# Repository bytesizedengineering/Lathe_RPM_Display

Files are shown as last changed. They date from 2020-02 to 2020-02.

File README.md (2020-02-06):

# Lathe_RPM_Display

See project on YouTube: https://youtu.be/7gDZs0bImr0
I bought a wood lathe a few months ago and I thought it would be fun to make my own digital readout. 
The plan for this project was to use a hall effect sensor and a neodymium magnet to sense the rotations of the lathe spindle. 
I used an arduino board to read the sensor, count the pulses, and calculate the RPM of the spindle. 
I used seven segment displays to show the RPM reading. I designed a PCB and 3D printed an enclosure.

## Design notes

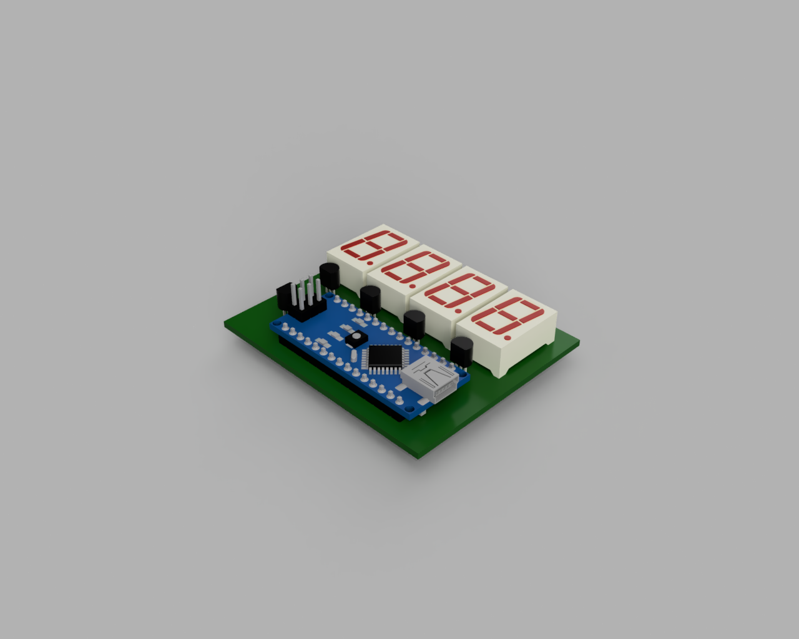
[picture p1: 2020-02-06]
Lathe RPM Display.PNG

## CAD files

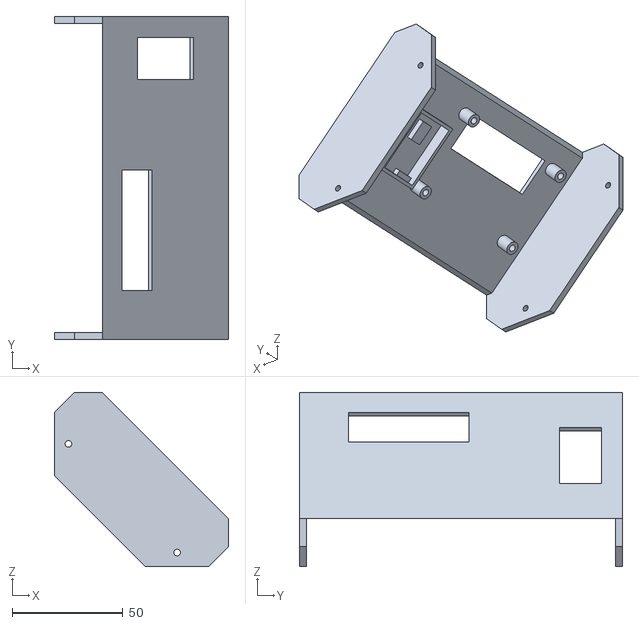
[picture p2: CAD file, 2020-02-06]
CAD/lid.stl
78.7 x 146.0 x 78.7

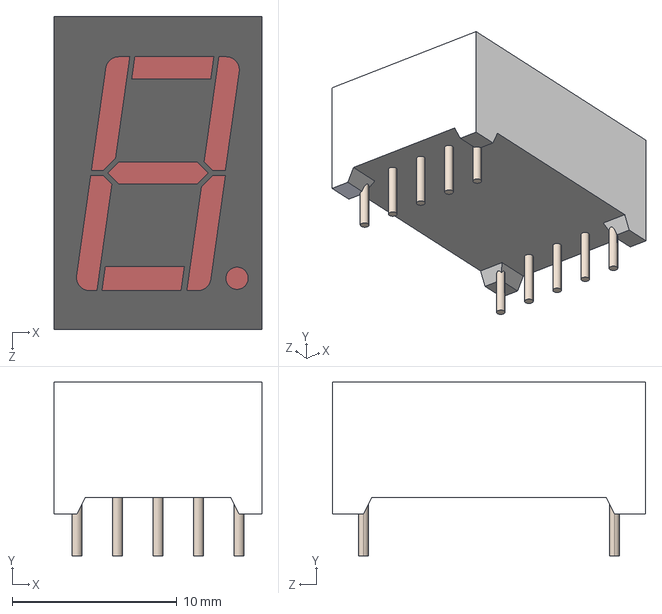
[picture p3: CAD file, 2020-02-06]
PCB/HSR8144B10 7Seg LED.STEP
12.6 x 10.6 x 19.0 mm

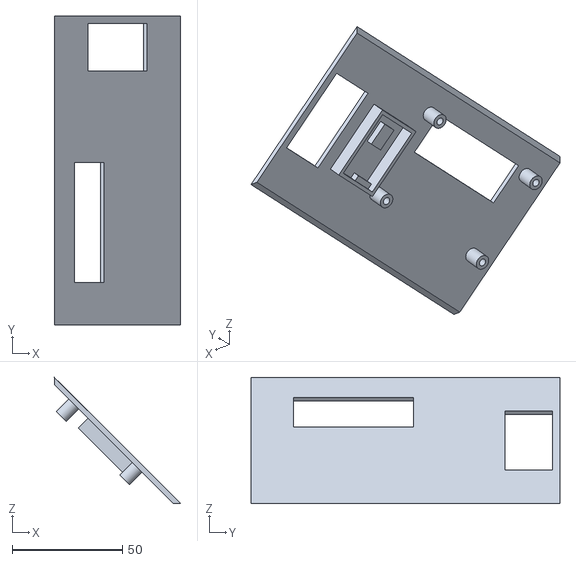
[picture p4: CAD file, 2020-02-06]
CAD/lid test print.stl
57.1 x 139.7 x 57.1

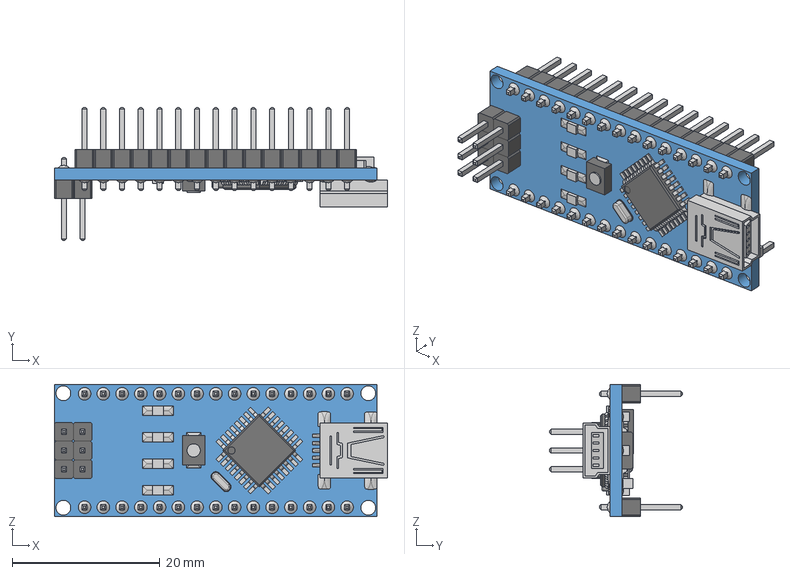
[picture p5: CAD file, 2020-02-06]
PCB/Arduino Nano V3.step
45.1 x 18.0 x 17.9 mm
switch
Led x 3
Led (1)
Pin x 21
chip1
USB
Crystal
Pin (1) x 15
Res x 5
cap x 2
Chip
respack x 2
diode
vreg

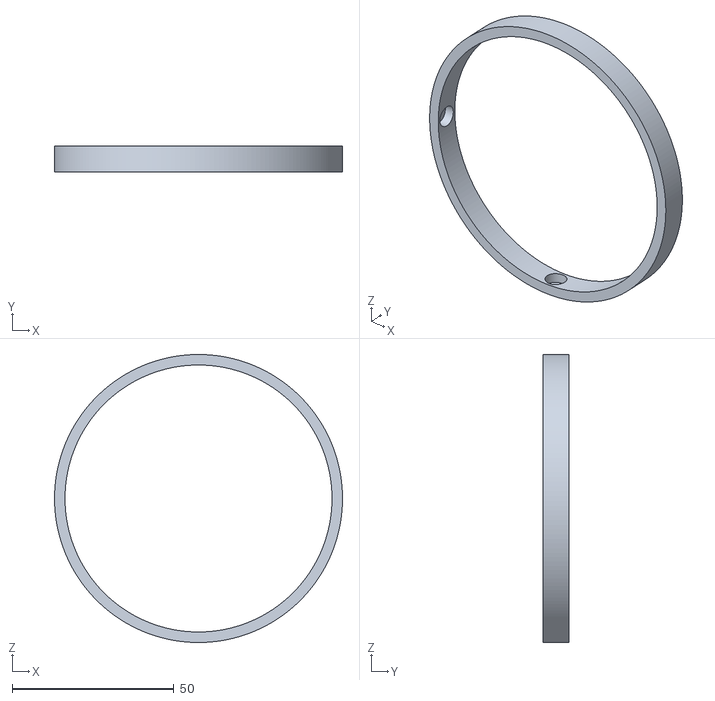
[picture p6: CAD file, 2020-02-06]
CAD/4 magnet ring.stl
89.0 x 8.00 x 89.0

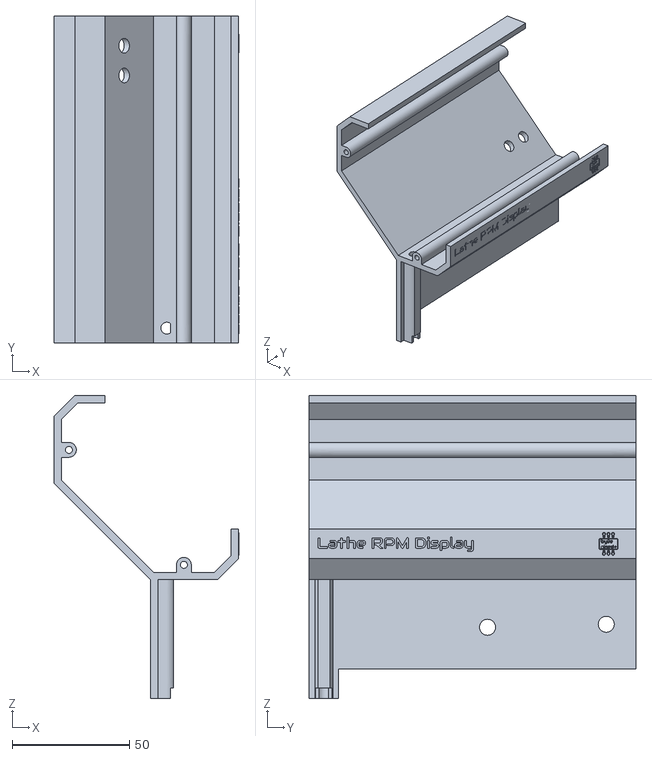
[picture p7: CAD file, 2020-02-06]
CAD/enclosure.stl
79.0 x 139.7 x 129.5

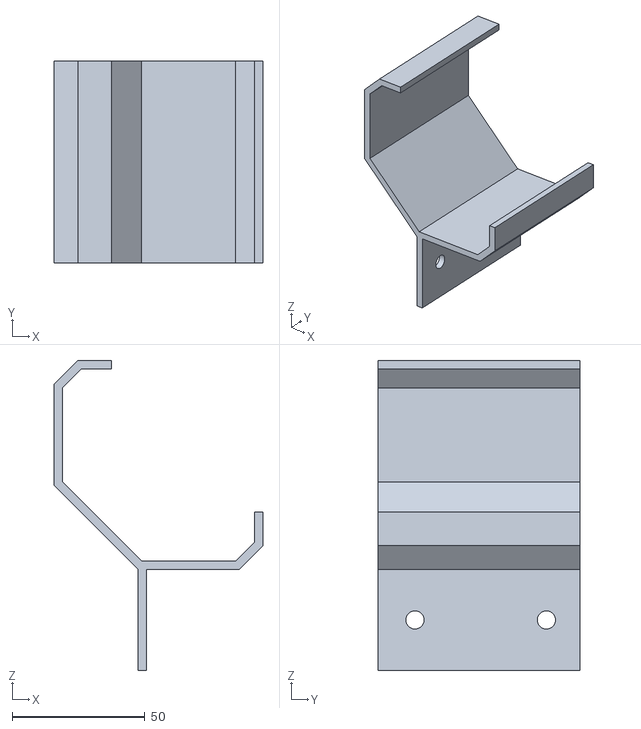
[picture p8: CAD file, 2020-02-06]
CAD/enclosure test print.stl
78.7 x 76.2 x 116.8

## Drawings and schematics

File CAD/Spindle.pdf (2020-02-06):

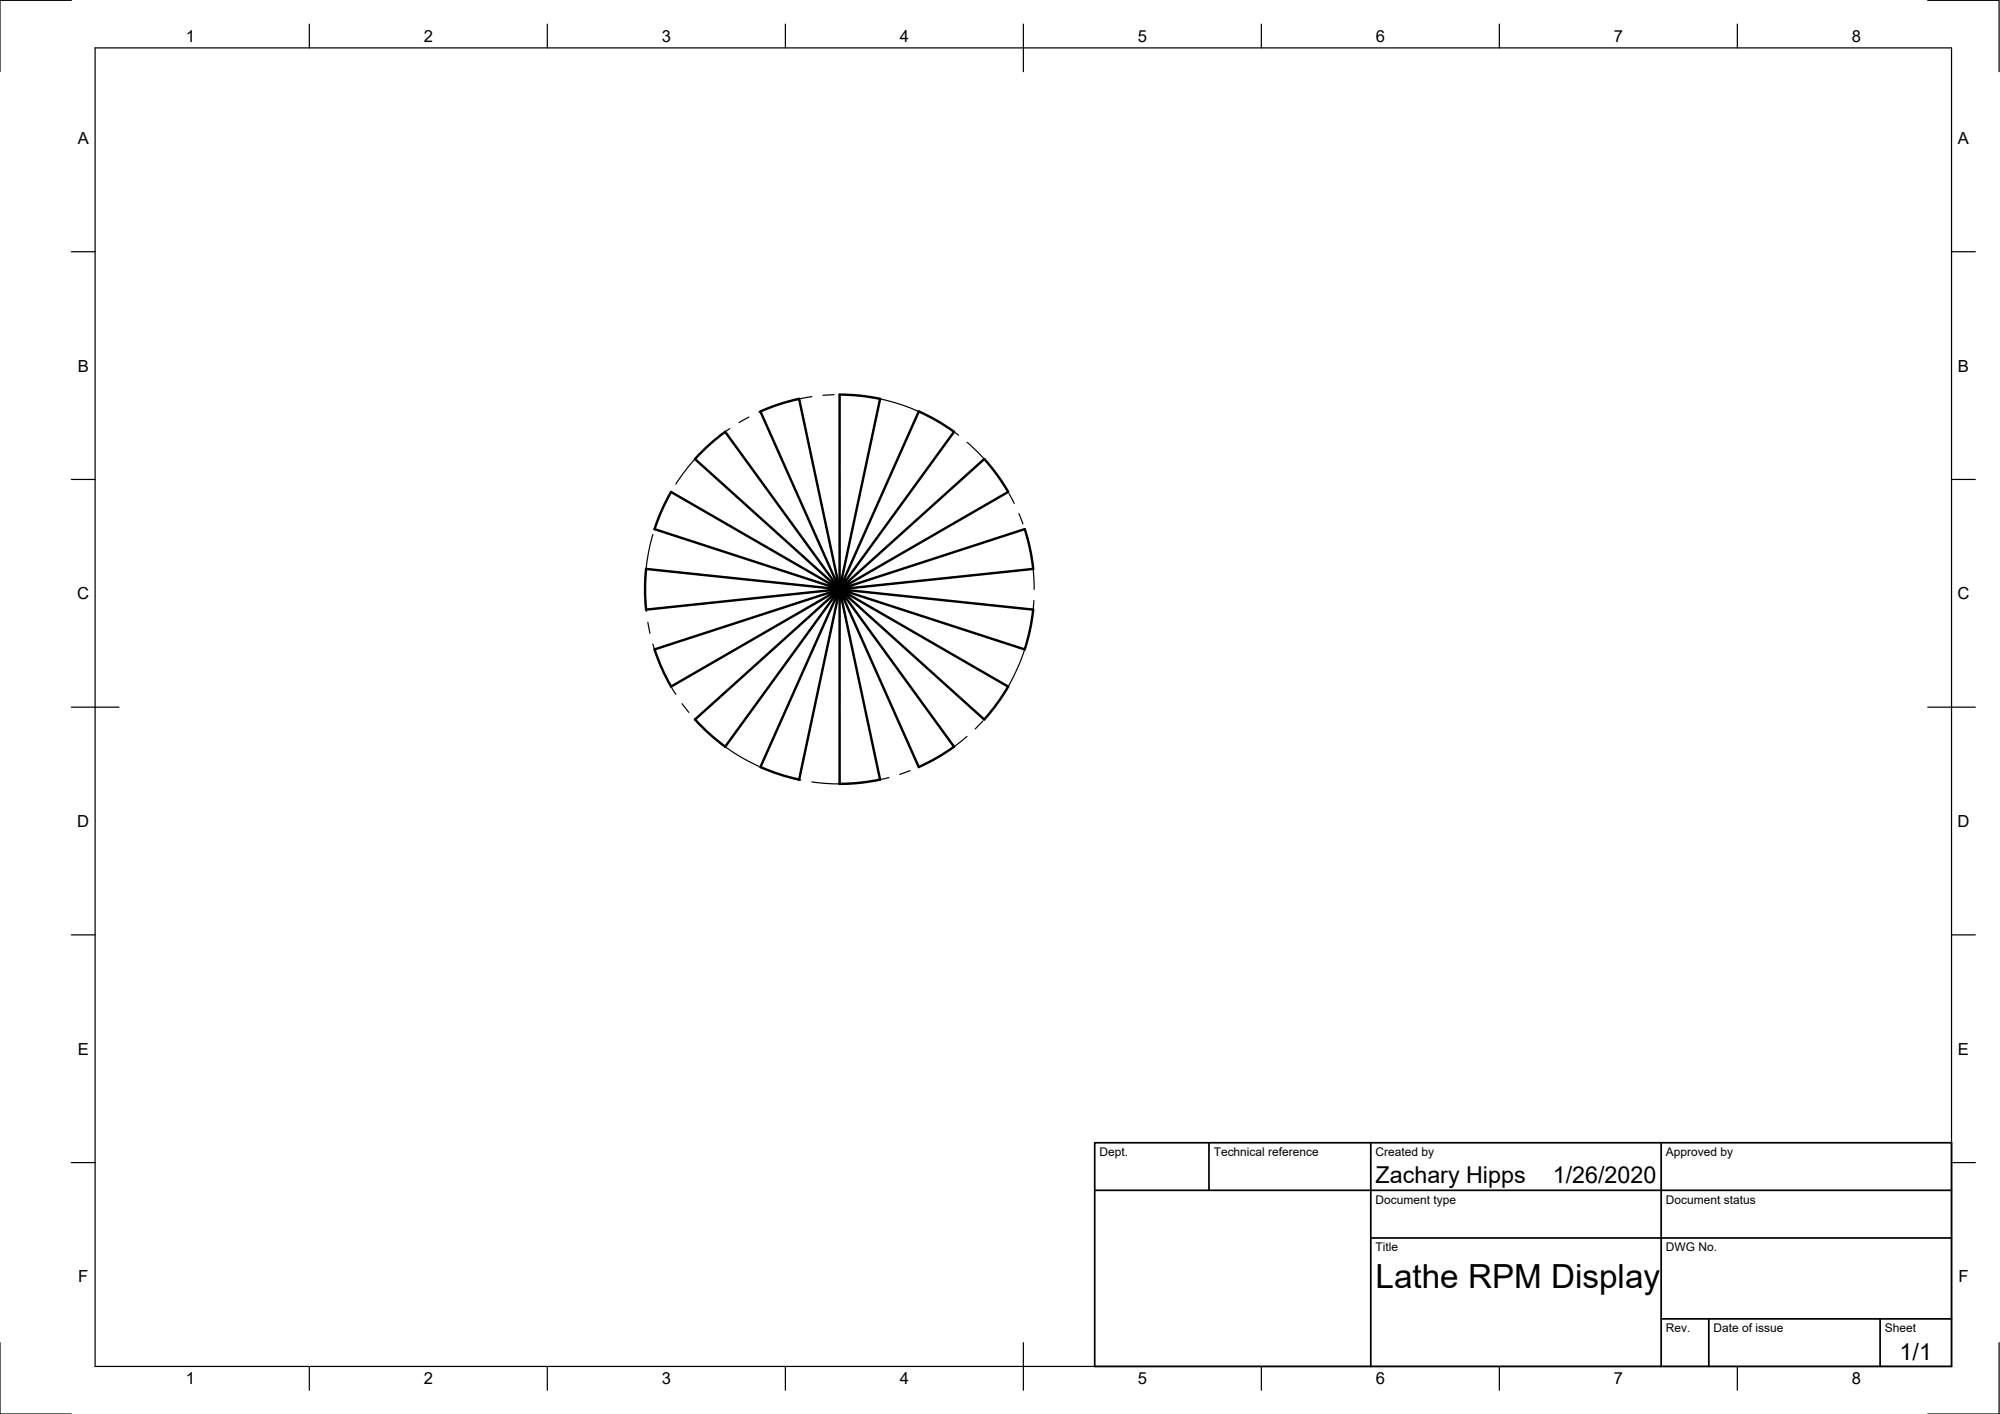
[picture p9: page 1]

Dept. | Technical reference | Created by Zachary Hipps 1/26/2020 | Approved by

Document type | Document status

Title Lathe RPM Display | DWG No.

Rev. | Date of issue | Sheet 1/1

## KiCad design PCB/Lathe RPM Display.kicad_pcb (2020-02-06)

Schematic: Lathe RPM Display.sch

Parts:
A1: Arduino_Nano_v3.x; Arduino_Nano
J1: Conn_01x02; PinSocket_1x02_P2.54mm_Vertical
Q1: A3144EU; TO-92-3; MPN OH090U; Digi-Key_PN 365-1001-ND
Q2, Q3, Q4, Q5: 2N7000; TO-92_Inline
R1, R2, R3, R4, R5, R6, R7, R8: 470; R_0805_2012Metric_Pad1.15x1.40mm_HandSolder
R9: 10k; R_0805_2012Metric_Pad1.15x1.40mm_HandSolder
U1, U2, U3, U4: KCSC02-105; 7SegmentLED_LTS6760_LTS6780

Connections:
+5V: A1.30 (VIN), J1.2, Q1.1, R9.2
/A: A1.19 (A0), R1.2
/B: A1.20 (A1), R2.2
/C: A1.21 (A2), R3.2
/D: A1.22 (A3), R4.2
/DP: A1.15 (D12), R8.2
/E: A1.23 (A4), R5.2
/F: A1.24 (A5), R6.2
/G: A1.16 (D13), R7.2
GND: A1.4 (GND), A1.29 (GND), J1.1, Q1.2, Q2.1, Q3.1, Q4.1, Q5.1
unnamed: A1.5 (D2), Q1.3, R9.1
unnamed: A1.7 (D4), Q3.2
unnamed: A1.8 (D5), Q2.2
unnamed: A1.9 (D6), Q5.2
unnamed: A1.10 (D7), Q4.2
unnamed: Q2.3, U1.3, U1.8
unnamed: Q3.3, U2.3, U2.8
unnamed: Q4.3, U3.3, U3.8
unnamed: Q5.3, U4.3, U4.8
unnamed: R1.1, U1.7, U2.7, U3.7, U4.7
unnamed: R2.1, U1.6, U2.6, U3.6, U4.6
unnamed: R3.1, U1.4, U2.4, U3.4, U4.4
unnamed: R4.1, U1.2, U2.2, U3.2, U4.2
unnamed: R5.1, U1.1, U2.1, U3.1, U4.1
unnamed: R6.1, U1.9, U2.9, U3.9, U4.9
unnamed: R7.1, U1.10, U2.10, U3.10, U4.10
unnamed: R8.1, U1.5, U2.5, U3.5, U4.5

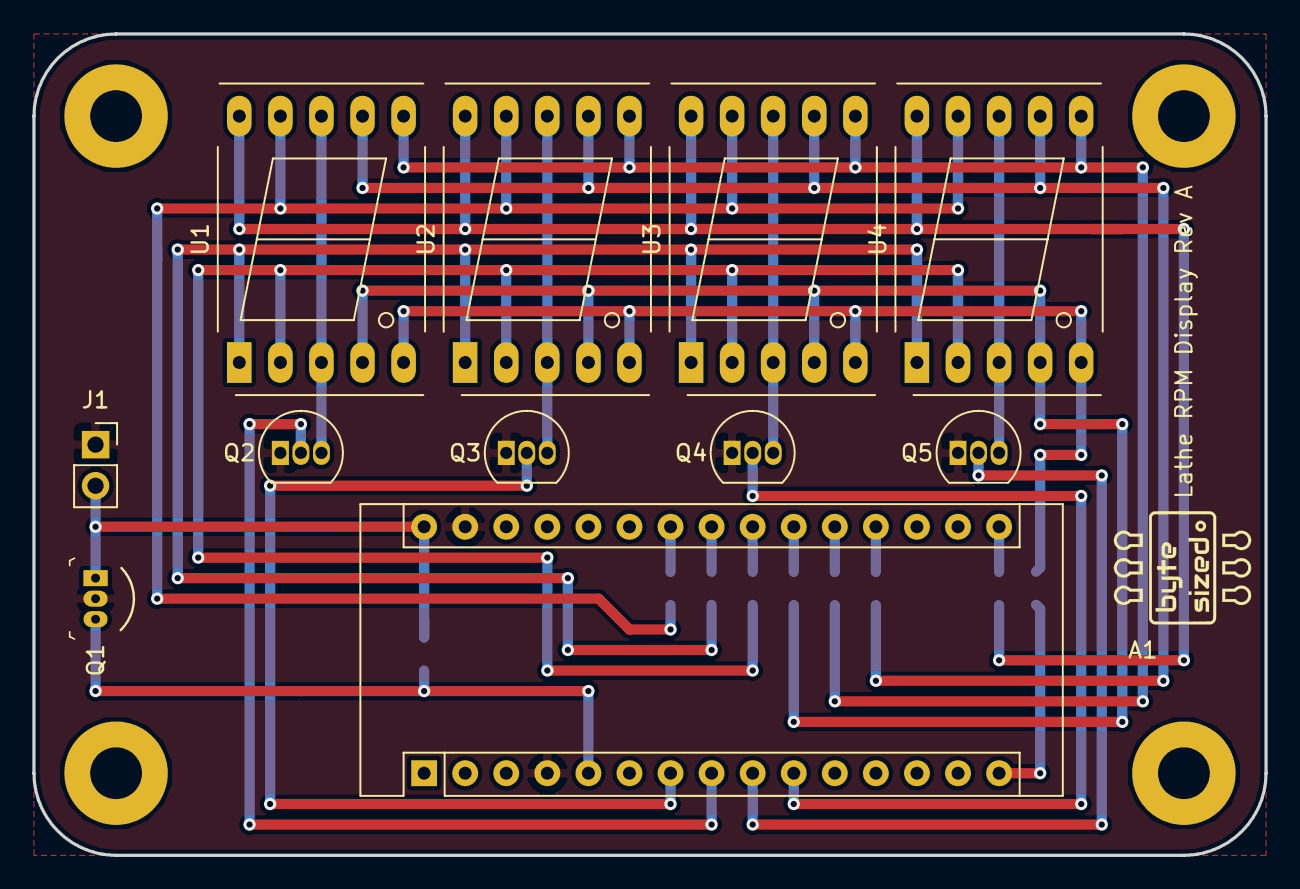
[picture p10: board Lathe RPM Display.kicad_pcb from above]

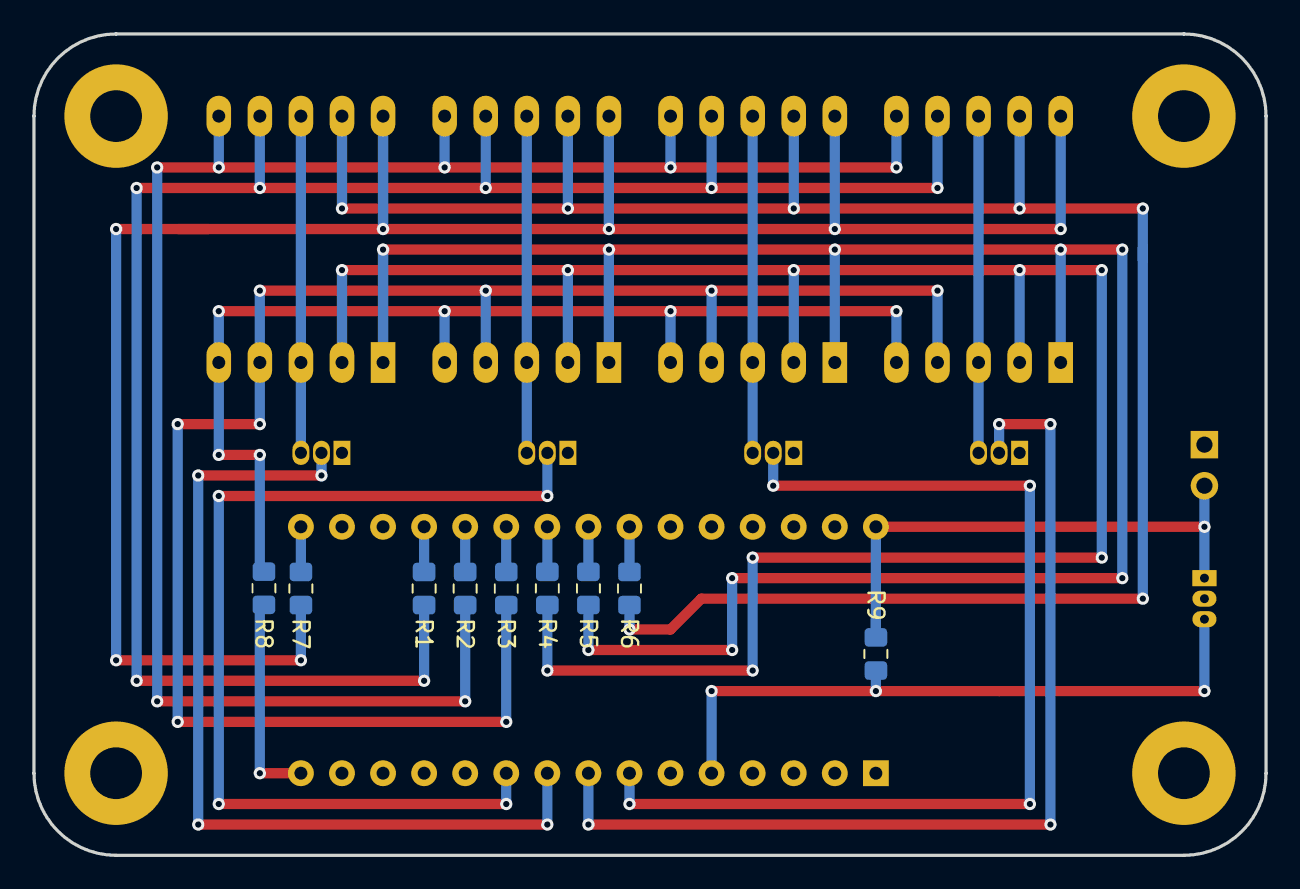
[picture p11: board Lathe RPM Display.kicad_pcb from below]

Board: 2 copper layers, 76.2 x 50.8 mm, 20 parts (9 on the bottom side), 27 nets.

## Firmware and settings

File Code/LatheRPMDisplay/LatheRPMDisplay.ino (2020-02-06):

#define SEGMENT_A 14
#define SEGMENT_B 15
#define SEGMENT_C 16
#define SEGMENT_D 17
#define SEGMENT_E 18
#define SEGMENT_F 19
#define SEGMENT_G 13
#define SEGMENT_DP 12

#define DIGIT_1 5
#define DIGIT_2 4
#define DIGIT_3 7
#define DIGIT_4 6

#define POV_DELAY 250 // delay in microseconds needed for persistance of vision
#define SAMPLE_TIME 2000 // millisecond delay between calculating rpm 
#define PULSE_PER_REV 2 // number of pulses per revolution of spindle

int segments[]={SEGMENT_A, SEGMENT_B, SEGMENT_C, SEGMENT_D, SEGMENT_E, SEGMENT_F, SEGMENT_G, SEGMENT_DP};
int digits[]={DIGIT_1,DIGIT_2,DIGIT_3,DIGIT_4};
unsigned long stopWatch = 0;

volatile int count = 0;
int buffer[120];
int bufferIndex=0;
int rpm = 0;
const int scaleFactor = 60000/SAMPLE_TIME/PULSE_PER_REV; // Multiply the pulse count by this value to scale up to RPM. This is also the resolution of RPM calculated.
void setup() {
	Serial.begin(9600);
	for(int i=0; i<8; i++){
		pinMode(segments[i],OUTPUT);
		digitalWrite(segments[i],LOW);
	}
  
	for(int i=0; i<4; i++){
		pinMode(digits[i],OUTPUT);
		digitalWrite(digits[i],LOW);
	}
	
	for(int i=0; i<120; i++){
		buffer[i]=0;
	}
	attachInterrupt(digitalPinToInterrupt(2), incrementCount, FALLING);	
}

void loop() {
		if(millis() - stopWatch > SAMPLE_TIME){
		rpm = count*scaleFactor; //Serial.println(rpm);
		count = 0;
		stopWatch = millis();
	}
	displayValue(rpm);	
}

void displayValue (int value){
	if(value < 10000 && value >= 0){
		int tempVal = value;
		int tempDigit = 0;
		tempDigit = tempVal/1000; displayDigit(tempDigit); digitalWrite(digits[0], HIGH); delayMicroseconds(POV_DELAY); clear(); digitalWrite(digits[0], LOW); tempVal = tempVal - tempDigit*1000;
		tempDigit = tempVal/100; displayDigit(tempDigit); digitalWrite(digits[1], HIGH); delayMicroseconds(POV_DELAY); clear(); digitalWrite(digits[1], LOW); tempVal = tempVal - tempDigit*100;
		tempDigit = tempVal/10; displayDigit(tempDigit); digitalWrite(digits[2], HIGH); delayMicroseconds(POV_DELAY); clear(); digitalWrite(digits[2], LOW); tempVal = tempVal - tempDigit*10;
		displayDigit(tempVal); digitalWrite(digits[3], HIGH); delayMicroseconds(POV_DELAY); clear(); digitalWrite(digits[3], LOW);
	}
	else{
		Serial.println("Error: value out of range");
	}
}

void displayDigit(int number){
	switch (number){
		case 0:
			digitalWrite(SEGMENT_A,HIGH); digitalWrite(SEGMENT_B,HIGH); digitalWrite(SEGMENT_C,HIGH); digitalWrite(SEGMENT_D,HIGH); digitalWrite(SEGMENT_E,HIGH); digitalWrite(SEGMENT_F,HIGH);
			break;
		case 1:
			digitalWrite(SEGMENT_B,HIGH); digitalWrite(SEGMENT_C,HIGH);
			break;
		case 2:
			digitalWrite(SEGMENT_A,HIGH); digitalWrite(SEGMENT_B,HIGH); digitalWrite(SEGMENT_D,HIGH); digitalWrite(SEGMENT_E,HIGH); digitalWrite(SEGMENT_G,HIGH);
			break;
		case 3:
			digitalWrite(SEGMENT_A,HIGH); digitalWrite(SEGMENT_B,HIGH); digitalWrite(SEGMENT_C,HIGH); digitalWrite(SEGMENT_D,HIGH); digitalWrite(SEGMENT_G,HIGH);
			break;
		case 4:
			digitalWrite(SEGMENT_B,HIGH); digitalWrite(SEGMENT_C,HIGH); digitalWrite(SEGMENT_F,HIGH); digitalWrite(SEGMENT_G,HIGH);
			break;
		case 5:
			digitalWrite(SEGMENT_A,HIGH); digitalWrite(SEGMENT_C,HIGH); digitalWrite(SEGMENT_D,HIGH); digitalWrite(SEGMENT_F,HIGH); digitalWrite(SEGMENT_G,HIGH);
			break;
		case 6:
			digitalWrite(SEGMENT_A,HIGH); digitalWrite(SEGMENT_C,HIGH); digitalWrite(SEGMENT_D,HIGH); digitalWrite(SEGMENT_E,HIGH); digitalWrite(SEGMENT_F,HIGH); digitalWrite(SEGMENT_G,HIGH);
			break;
		case 7:
			digitalWrite(SEGMENT_A,HIGH); digitalWrite(SEGMENT_B,HIGH); digitalWrite(SEGMENT_C,HIGH);
			break;
		case 8:
			digitalWrite(SEGMENT_A,HIGH); digitalWrite(SEGMENT_B,HIGH); digitalWrite(SEGMENT_C,HIGH); digitalWrite(SEGMENT_D,HIGH); digitalWrite(SEGMENT_E,HIGH); digitalWrite(SEGMENT_F,HIGH); digitalWrite(SEGMENT_G,HIGH);
			break;
		case 9:
			digitalWrite(SEGMENT_A,HIGH); digitalWrite(SEGMENT_B,HIGH); digitalWrite(SEGMENT_C,HIGH); digitalWrite(SEGMENT_D,HIGH); digitalWrite(SEGMENT_F,HIGH); digitalWrite(SEGMENT_G,HIGH);
			break;
		default:
			digitalWrite(SEGMENT_A,LOW); digitalWrite(SEGMENT_B,LOW); digitalWrite(SEGMENT_C,LOW); digitalWrite(SEGMENT_D,LOW); digitalWrite(SEGMENT_E,LOW); digitalWrite(SEGMENT_F,LOW); digitalWrite(SEGMENT_G,LOW);
	}
}

void clear(){
		digitalWrite(SEGMENT_A,LOW); digitalWrite(SEGMENT_B,LOW); digitalWrite(SEGMENT_C,LOW); digitalWrite(SEGMENT_D,LOW); digitalWrite(SEGMENT_E,LOW); digitalWrite(SEGMENT_F,LOW); digitalWrite(SEGMENT_G,LOW);
}

void incrementCount(){
	count++;
}

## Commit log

2019-11-19 Initial PCB and Code upload
    [Lathe RPM Display.kicad_pcb, Lathe RPM Display.sch, _saved_Lathe RPM Display.sch]
2019-11-22 Update LatheRPMDisplay.ino
    Seven segment displays how many seconds since last reset
    [LatheRPMDisplay.ino]
2019-11-24 code, schematic and layout
    Got code to a good working state. Schematic is good, maybe a couple more additions for power. Started layout and happy with locations. No traces routed.
    [Lathe RPM Display.kicad_pcb, Lathe RPM Display.sch, _saved_Lathe RPM Display.sch]
2020-02-06 hall effect fix
    Adjusted pulses per revolution to fix hall effect sensor double pulse
    [4 magnet ring.stl, Arduino Nano V3.step, HSR8144B10 7Seg LED.STEP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]
